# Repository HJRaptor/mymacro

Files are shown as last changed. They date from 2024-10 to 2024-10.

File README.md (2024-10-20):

# HackPad
## My experience
As part of **Hack Club’s HACKPAD YSWS** program, I embarked on a rewarding journey to build my own DIY macropad. This experience allowed me to explore various technical disciplines, from designing a custom **PCB in KiCAD** to **coding my very own firmware with QMK**. The most challenging aspect of the project was undoubtedly the PCB design. It required extensive research into component specifications, navigating datasheets, and ensuring that each part—switches, diodes, microcontrollers—was properly integrated into the design. The process of **placing components and routing the traces** was the most time-consuming and working through these challenges gave me a much deeper understanding of electronics design.

On the other hand, the part I enjoyed the most was **working with CAD**. With my existing CAD skills, I was able to confidently create a functional layout for the macropad’s physical structure. Translating these skills into real-world applications for a product I could use was fulfilling and rewarding. Coding the firmware was surprisingly straightforward, thanks to QMK's user-friendly environment, making the software side of things much simpler than anticipated. 
***Overall, this project was an invaluable learning experience that not only introduced me to PCB design but also allowed me to merge my existing skills with new knowledge to create something functional.***
## Bill Of Materials

    Xiao RP2040
    PCF8574 IO expander
    SSD1306 0.96 OLED
    (2) 4.7k resistor
    (16) SK6812 LED
    (16) 1N4148 diodes
    (16) Cherry MX brown switches

    (16) any keycaps at hq
    (16) Mill-Max 0305s hotswap socket
    (2) any encoder knobs at hq
    (2) EC11 encoder
    
    **--> Please laser cut the plate in 3mm clear acrylic and 3D print the rest of the pieces.**

### My Model
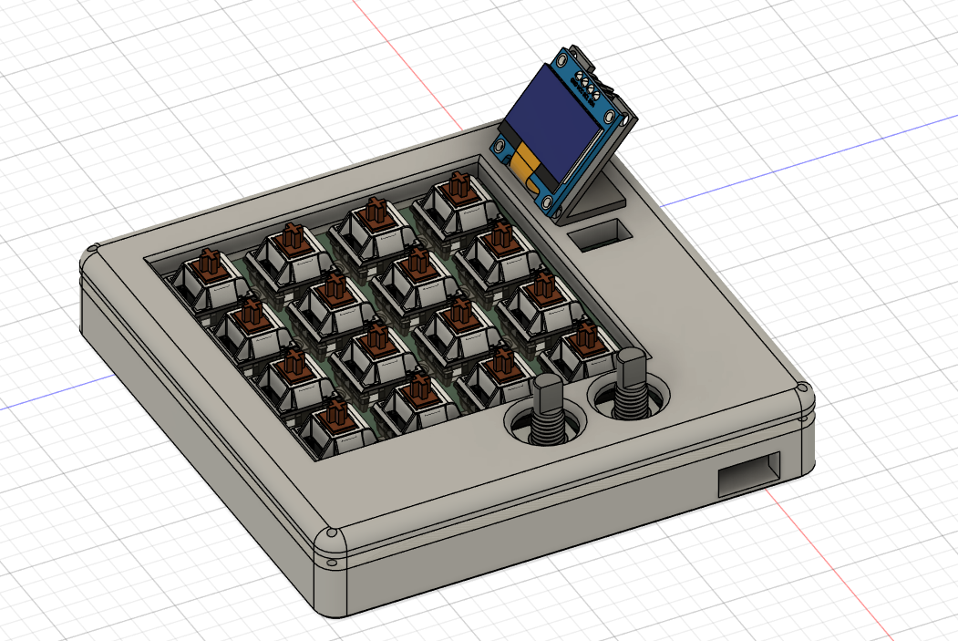
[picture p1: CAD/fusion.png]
fusion


### My schematic
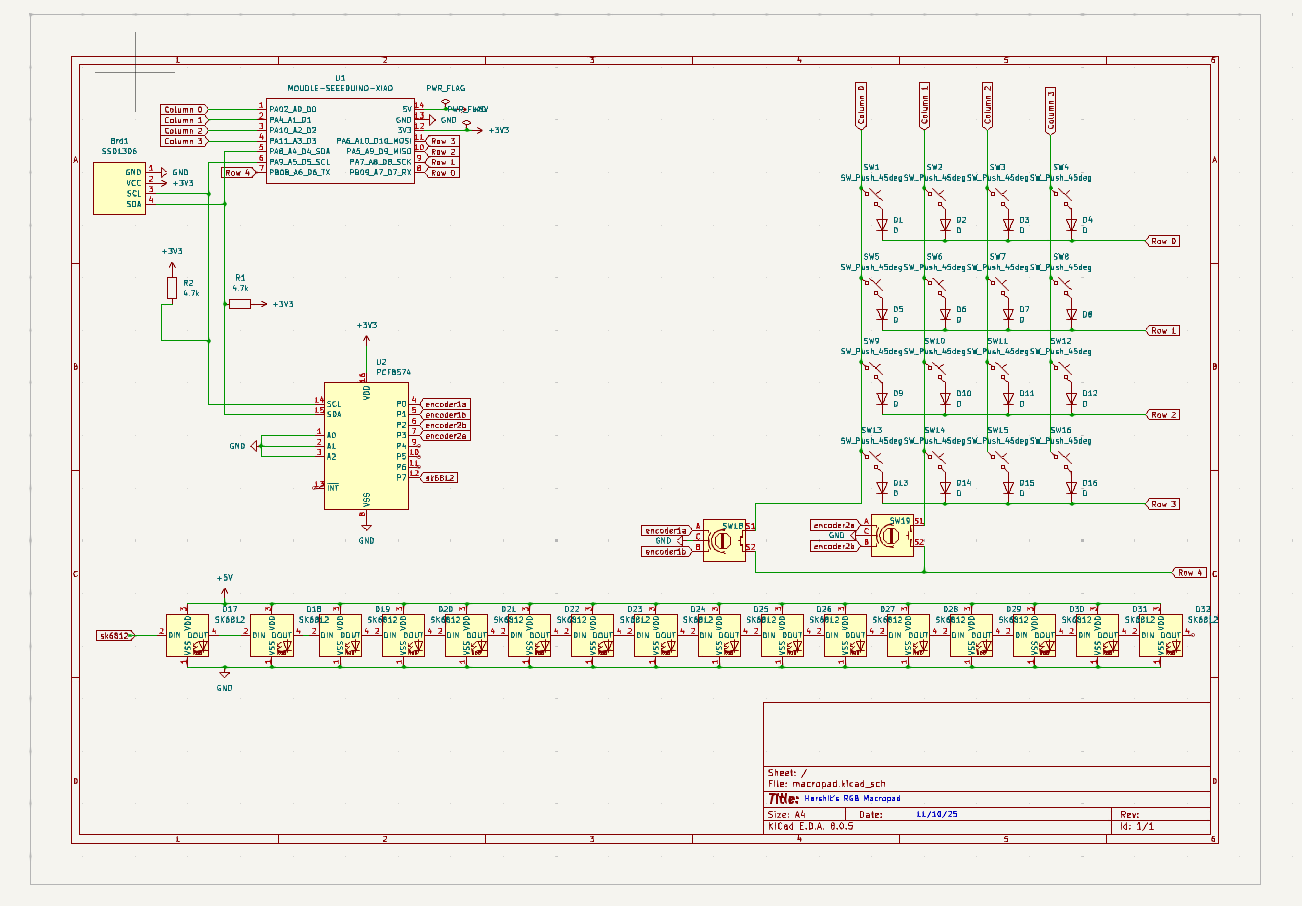
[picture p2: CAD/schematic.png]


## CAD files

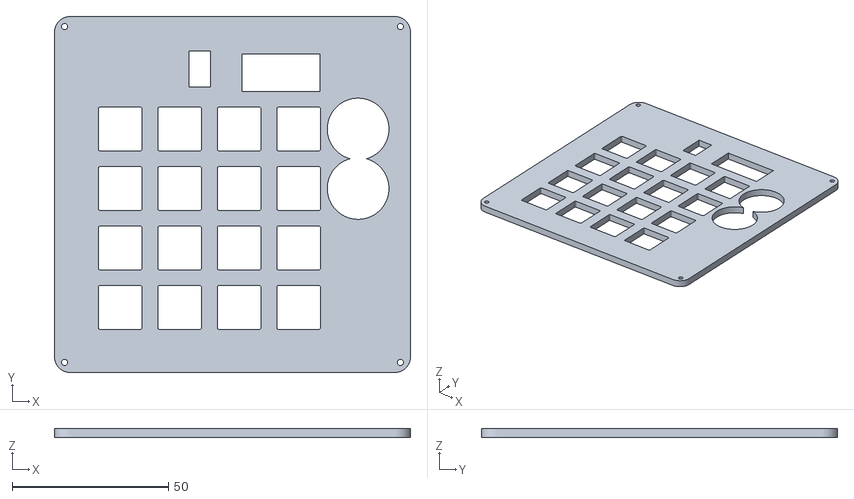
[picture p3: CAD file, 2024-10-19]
Production/case/plate.dxf
114.0 x 114.0 x 3.00

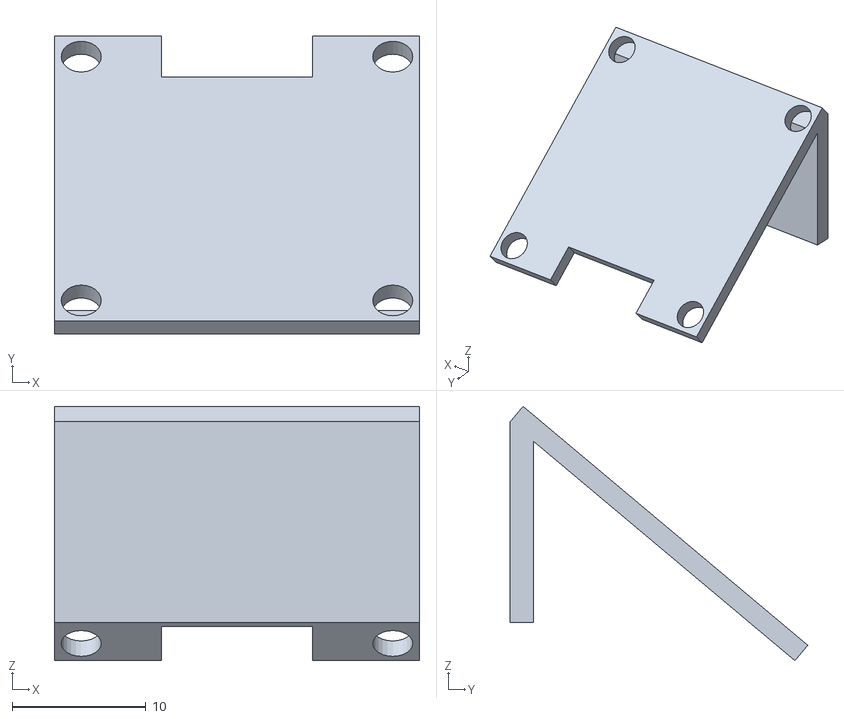
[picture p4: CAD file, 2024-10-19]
Production/case/oledstand.stl
27.3 x 22.3 x 19.0

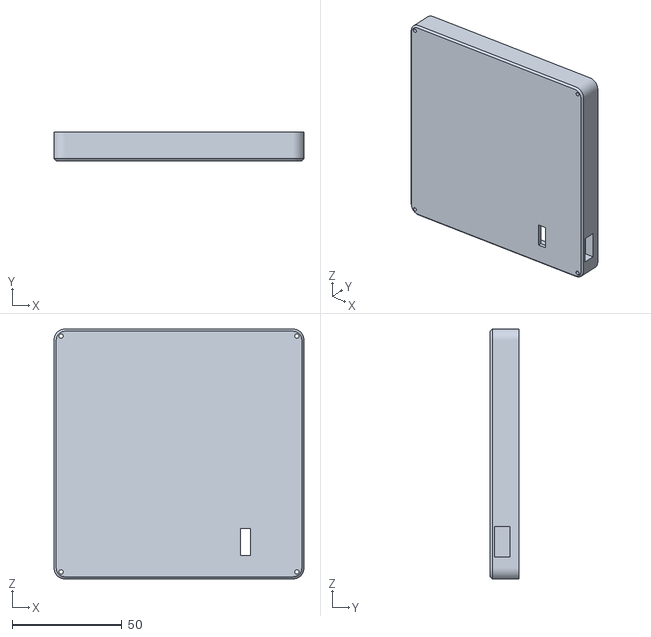
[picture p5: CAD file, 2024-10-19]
Production/case/base.stl
114.0 x 13.0 x 114.0

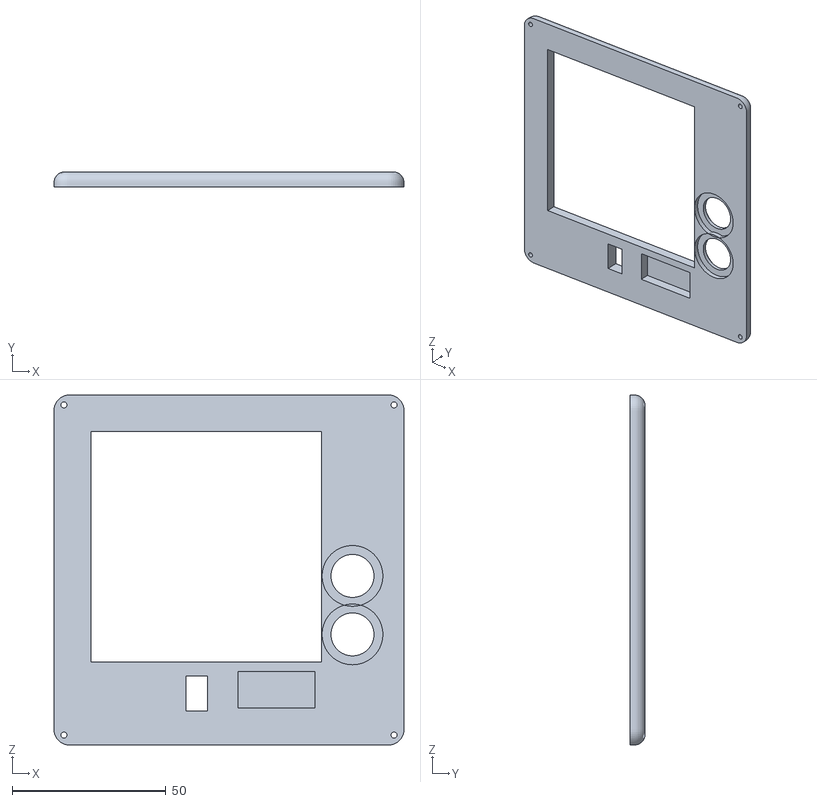
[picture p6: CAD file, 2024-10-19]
Production/case/top case part.stl
114.0 x 5.00 x 114.0

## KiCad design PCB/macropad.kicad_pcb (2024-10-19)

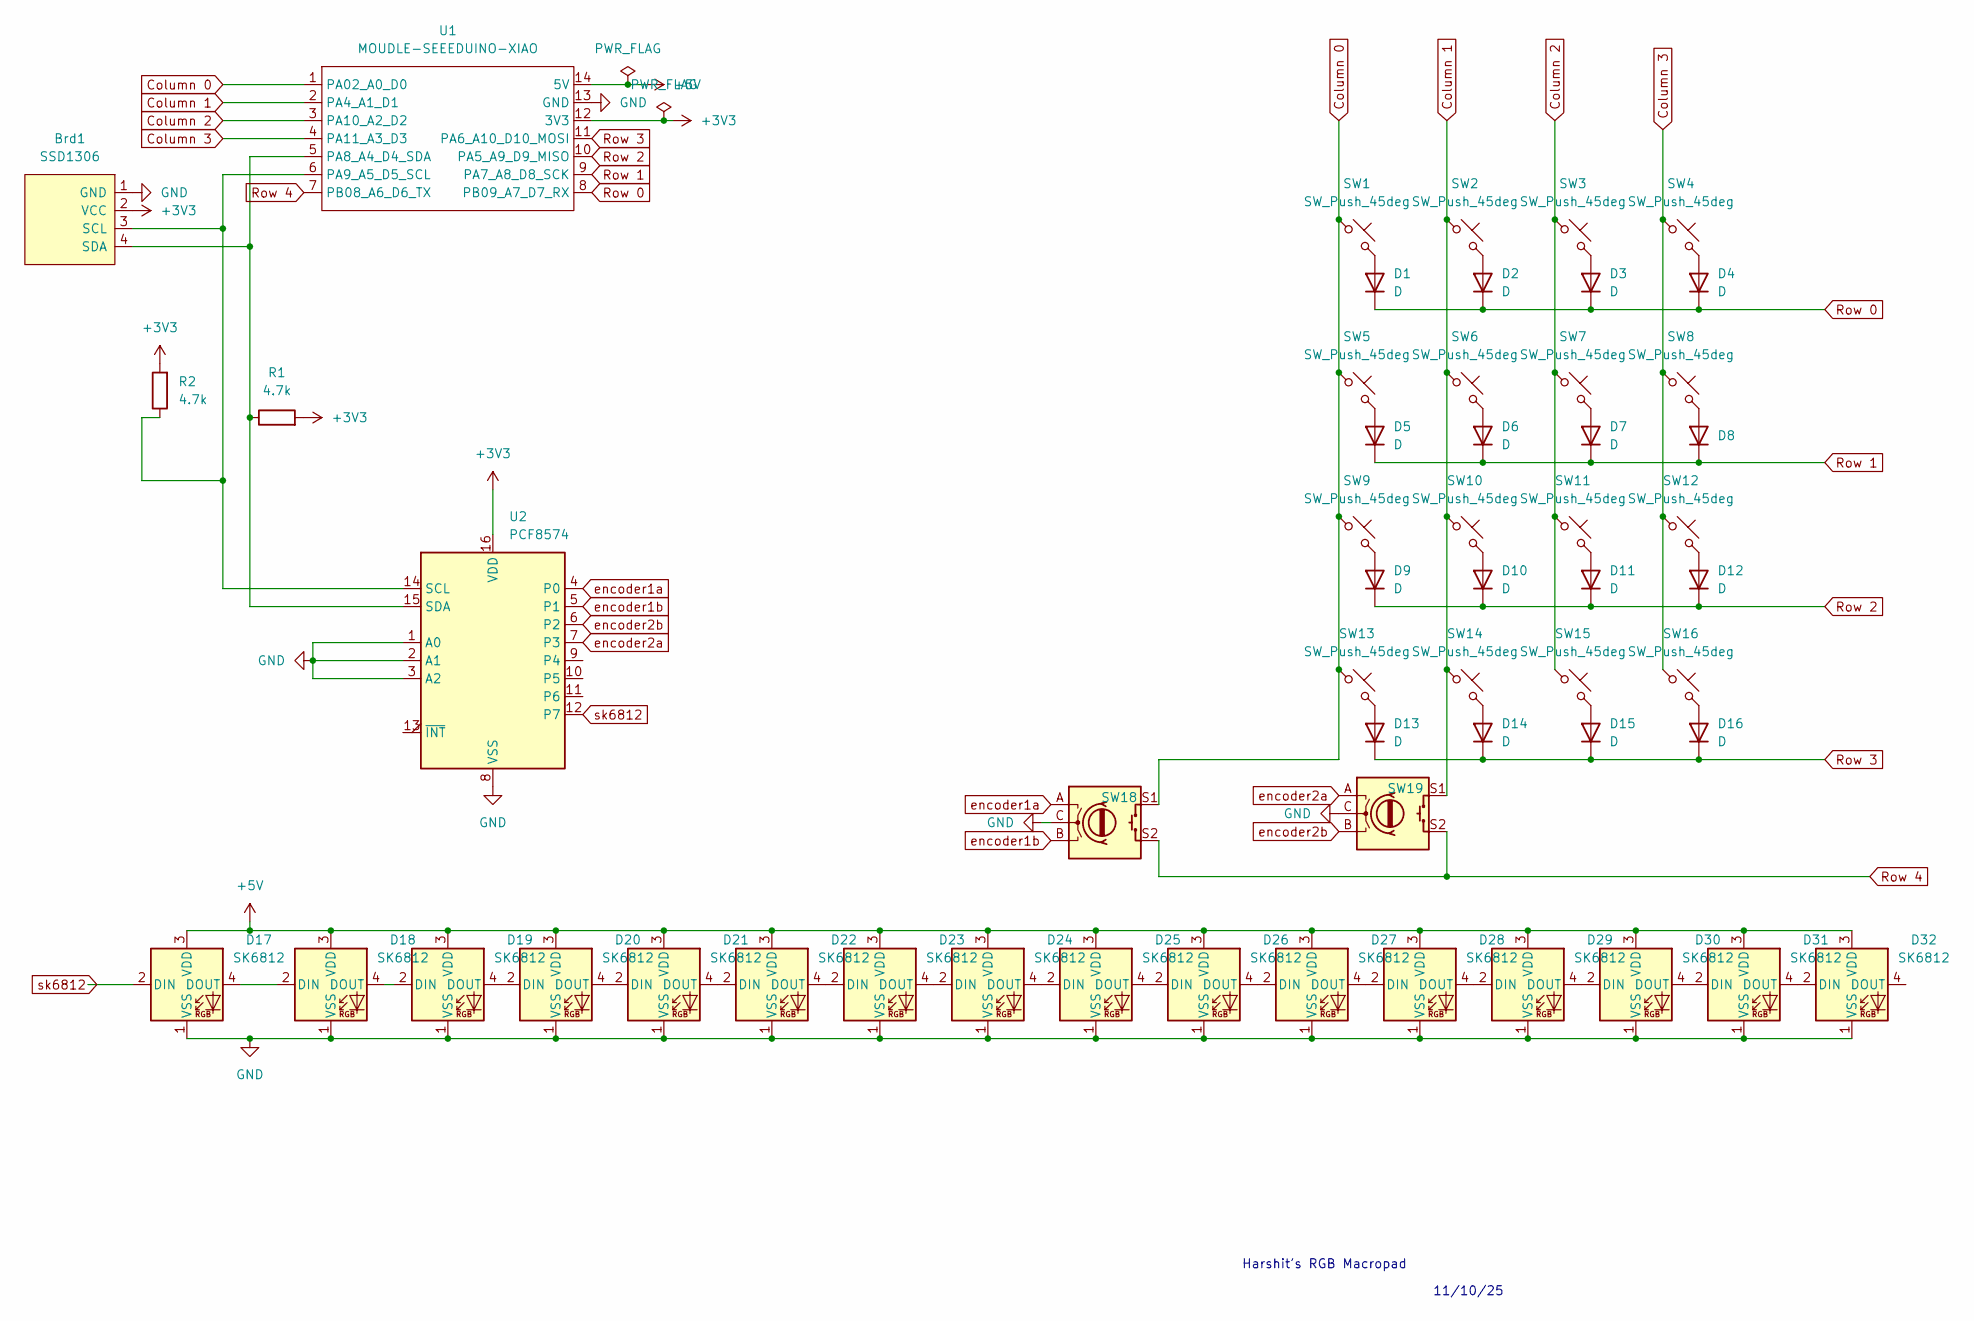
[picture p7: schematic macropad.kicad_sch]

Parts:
Brd1: SSD1306; 128x64OLED
D1, D2, D3, D4, D5, D6, D7, D8, D9, D10, D11, D12, D13, D14, D15, D16: D; D_DO-35_SOD27_P7.62mm_Horizontal
D17, D18, D19, D20, D21, D22, D23, D24, D25, D26, D27, D28, D29, D30, D31, D32: SK6812; LED_SK6812_PLCC4_5.0x5.0mm_P3.2mm
R1, R2: 4.7k; R_Axial_DIN0204_L3.6mm_D1.6mm_P5.08mm_Horizontal
SW1, SW2, SW3, SW4, SW5, SW6, SW7, SW8, SW9, SW10, SW11, SW12, SW13, SW14, SW15, SW16: SW_Push_45deg; SW_Cherry_MX_1.00u_PCB
SW18, SW19: RotaryEncoder_Switch; RotaryEncoder_Alps_EC11E-Switch_Vertical_H20mm
U1: MOUDLE-SEEEDUINO-XIAO; MOUDLE14P-2.54-21X17.8MM
U2: PCF8574; N16

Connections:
+3V3: Brd1.2 (VCC), R1.2, R2.2, U1.12 (3V3), U2.16 (VDD)
+5V: D17.3 (VDD), D18.3 (VDD), D19.3 (VDD), D20.3 (VDD), D21.3 (VDD), D22.3 (VDD), D23.3 (VDD), D24.3 (VDD), D25.3 (VDD), D26.3 (VDD), D27.3 (VDD), D28.3 (VDD), D29.3 (VDD), D30.3 (VDD), D31.3 (VDD), D32.3 (VDD), U1.14 (5V)
Column 0: SW1.1, SW5.1, SW9.1, SW13.1, SW18.S1, U1.1 (PA02_A0_D0)
Column 1: SW2.1, SW6.1, SW10.1, SW14.1, SW19.S1, U1.2 (PA4_A1_D1)
Column 2: SW3.1, SW7.1, SW11.1, SW15.1, U1.3 (PA10_A2_D2)
Column 3: SW4.1, SW8.1, SW12.1, SW16.1, U1.4 (PA11_A3_D3)
GND: Brd1.1 (GND), D17.1 (VSS), D18.1 (VSS), D19.1 (VSS), D20.1 (VSS), D21.1 (VSS), D22.1 (VSS), D23.1 (VSS), D24.1 (VSS), D25.1 (VSS), D26.1 (VSS), D27.1 (VSS), D28.1 (VSS), D29.1 (VSS), D30.1 (VSS), D31.1 (VSS), D32.1 (VSS), SW18.C, SW19.C, U1.13 (GND), U2.1 (A0), U2.2 (A1), U2.3 (A2), U2.8 (VSS)
unnamed: Brd1.3 (SCL), R2.1, U1.6 (PA9_A5_D5_SCL), U2.14 (SCL)
unnamed: Brd1.4 (SDA), R1.1, U1.5 (PA8_A4_D4_SDA), U2.15 (SDA)
unnamed: D1.2 (A), SW1.2
unnamed: D2.2 (A), SW2.2
unnamed: D3.2 (A), SW3.2
unnamed: D4.2 (A), SW4.2
unnamed: D5.2 (A), SW5.2
unnamed: D6.2 (A), SW6.2
unnamed: D7.2 (A), SW7.2
unnamed: D8.2 (A), SW8.2
unnamed: D9.2 (A), SW9.2
unnamed: D10.2 (A), SW10.2
unnamed: D11.2 (A), SW11.2
unnamed: D12.2 (A), SW12.2
unnamed: D13.2 (A), SW13.2
unnamed: D14.2 (A), SW14.2
unnamed: D15.2 (A), SW15.2
unnamed: D16.2 (A), SW16.2
unnamed: D17.4 (DOUT), D18.2 (DIN)
unnamed: D18.4 (DOUT), D19.2 (DIN)
unnamed: D19.4 (DOUT), D20.2 (DIN)
unnamed: D20.4 (DOUT), D21.2 (DIN)
unnamed: D21.4 (DOUT), D22.2 (DIN)
unnamed: D22.4 (DOUT), D23.2 (DIN)
unnamed: D23.4 (DOUT), D24.2 (DIN)
unnamed: D24.4 (DOUT), D25.2 (DIN)
unnamed: D25.4 (DOUT), D26.2 (DIN)
unnamed: D26.4 (DOUT), D27.2 (DIN)
unnamed: D27.4 (DOUT), D28.2 (DIN)
unnamed: D28.4 (DOUT), D29.2 (DIN)
unnamed: D29.4 (DOUT), D30.2 (DIN)
unnamed: D30.4 (DOUT), D31.2 (DIN)
unnamed: D31.4 (DOUT), D32.2 (DIN)
Row 0: D1.1 (K), D2.1 (K), D3.1 (K), D4.1 (K), U1.8 (PB09_A7_D7_RX)
Row 1: D5.1 (K), D6.1 (K), D7.1 (K), D8.1 (K), U1.9 (PA7_A8_D8_SCK)
Row 2: D9.1 (K), D10.1 (K), D11.1 (K), D12.1 (K), U1.10 (PA5_A9_D9_MISO)
Row 3: D13.1 (K), D14.1 (K), D15.1 (K), D16.1 (K), U1.11 (PA6_A10_D10_MOSI)
Row 4: SW18.S2, SW19.S2, U1.7 (PB08_A6_D6_TX)
encoder1a: SW18.A, U2.4 (P0)
encoder1b: SW18.B, U2.5 (P1)
encoder2a: SW19.A, U2.7 (P3)
encoder2b: SW19.B, U2.6 (P2)
sk6812: D17.2 (DIN), U2.12 (P7)

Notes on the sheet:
11/10/25
Harshit's RGB Macropad

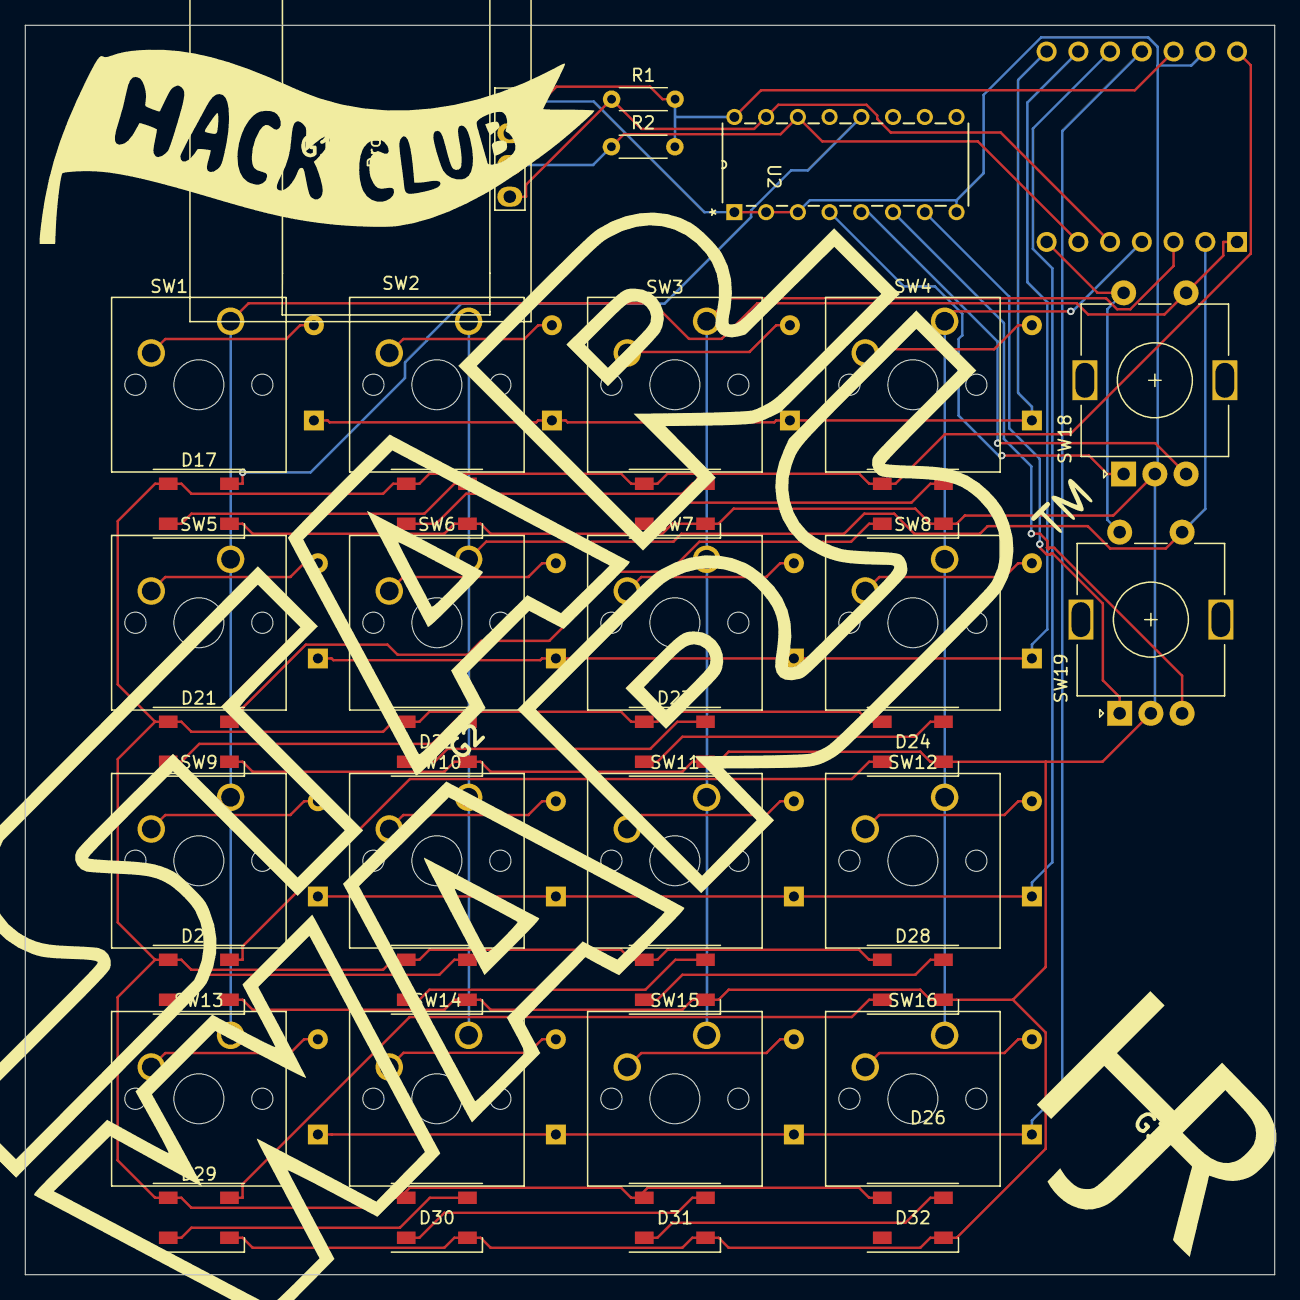
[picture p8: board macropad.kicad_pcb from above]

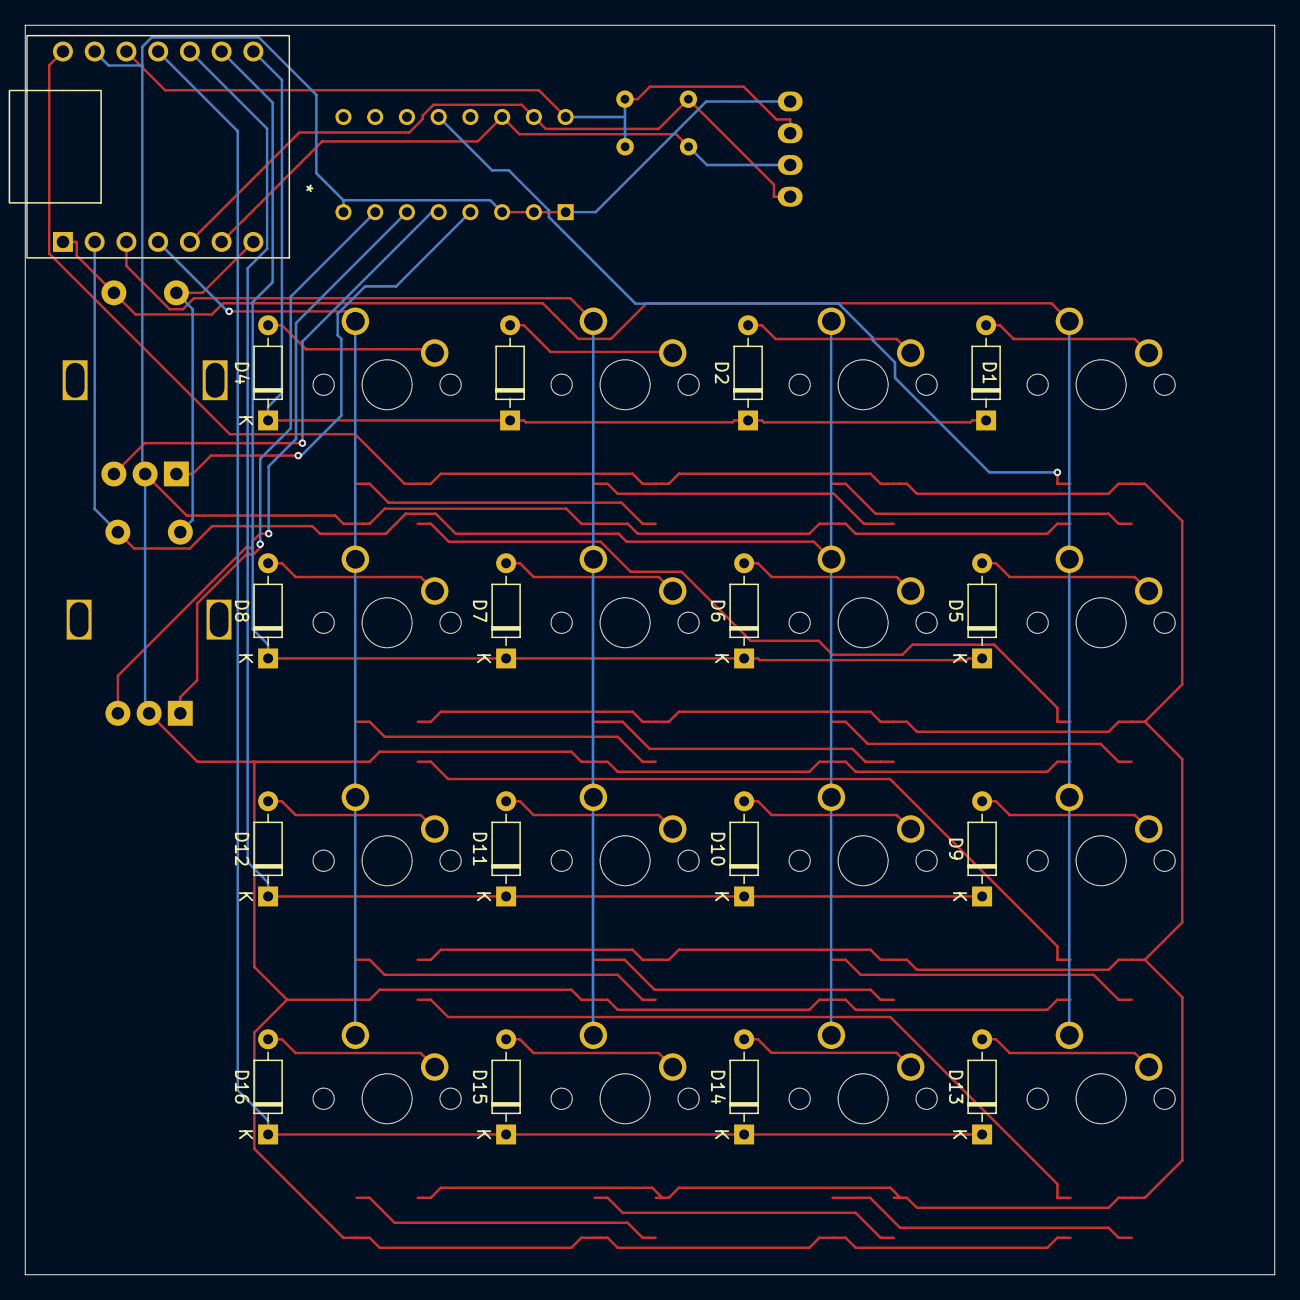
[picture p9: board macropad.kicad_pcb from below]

Board: 2 copper layers, 100.0 x 100.0 mm, 58 parts (17 on the bottom side), 50 nets.

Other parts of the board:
G1, G2, G3: LOGO

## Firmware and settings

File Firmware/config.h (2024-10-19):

#pragma once

// PCF8574 configuration
#define PCF8574_I2C_ADDRESS 0x20 // Set your I2C address for the PCF8574 here

// Encoder definitions
#define NUM_ENCODERS 2

//#define WS2812_DI_PIN D7
//#define WS2812_DI_PIN (PCF8574_ADDRESS << 1 | 7) // P7 on the PCF8574

// Define the pins for the encoders on PCF8574
// Assuming encoder 1 A and B are connected to PCF8574 pins 0 and 1
#define ENCODER_A_PIN_0 (PCF8574_ADDRESS << 1 | 0)  // PCF8574 pin 0
#define ENCODER_A_PIN_1 (PCF8574_ADDRESS << 1 | 1)  // PCF8574 pin 1
#define ENCODER_B_PIN_0 (PCF8574_ADDRESS << 1 | 3)  // PCF8574 pin 2
#define ENCODER_B_PIN_1 (PCF8574_ADDRESS << 1 | 2)  // PCF8574 pin 3

// Additional configuration for using PCF8574 as encoder inputs
#define ENCODER_ROTARY_0_ENCODER_TYPE PCF8574_ENCODER
#define ENCODER_ROTARY_1_ENCODER_TYPE PCF8574_ENCODER


// SSD1306 OLED display configuration
#define OLED_DRIVER_TYPE SSD1306
#define OLED_I2C_ADDRESS 0x3C // Set your I2C address for the SSD1306 here
#define OLED_DISPLAY_WIDTH 128
#define OLED_DISPLAY_HEIGHT 64

// Other configurations can be added below
//#define RGBLIGHT_LED_COUNT 16 // or however many LEDs you are using

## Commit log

2024-10-19 Add cad and firmware
2024-10-19 Uploading rest of the files
    [base.stl, macropad.kicad_pcb, macropad.kicad_sch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]
2024-10-19 update dxf
    [plate.dxf]
